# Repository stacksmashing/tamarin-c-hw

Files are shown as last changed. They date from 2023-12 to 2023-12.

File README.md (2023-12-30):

# Tamarin-C Hardware

This is the PCB for the [Tamarin-C firmware](https://github.com/stacksmashing/tamarin-c).

A tool to explore USB-C on Apple devices using the [Tamarin C Hardware](https://github.com/stacksmashing/tamarin-c-hw).

It is based on the [Central Scrutinizer by Marc Zyngier](https://git.kernel.org/pub/scm/linux/kernel/git/maz/cs-hw.git/).

If you're assembling one: An interactive BOM is included with this repository.

## License

This hardware is licensed under [CC BY-NC](https://creativecommons.org/licenses/by-nc/4.0/) - the Creative Commons Attribution-NonCommercial 4.0 International liecnse.

## Thanks

[Aisler](https://aisler.net) was nice enough to make a last-minute run for 37c3 possible, and additionally sponsored a hundred PCBs to give out at the conference. Thanks a lot!

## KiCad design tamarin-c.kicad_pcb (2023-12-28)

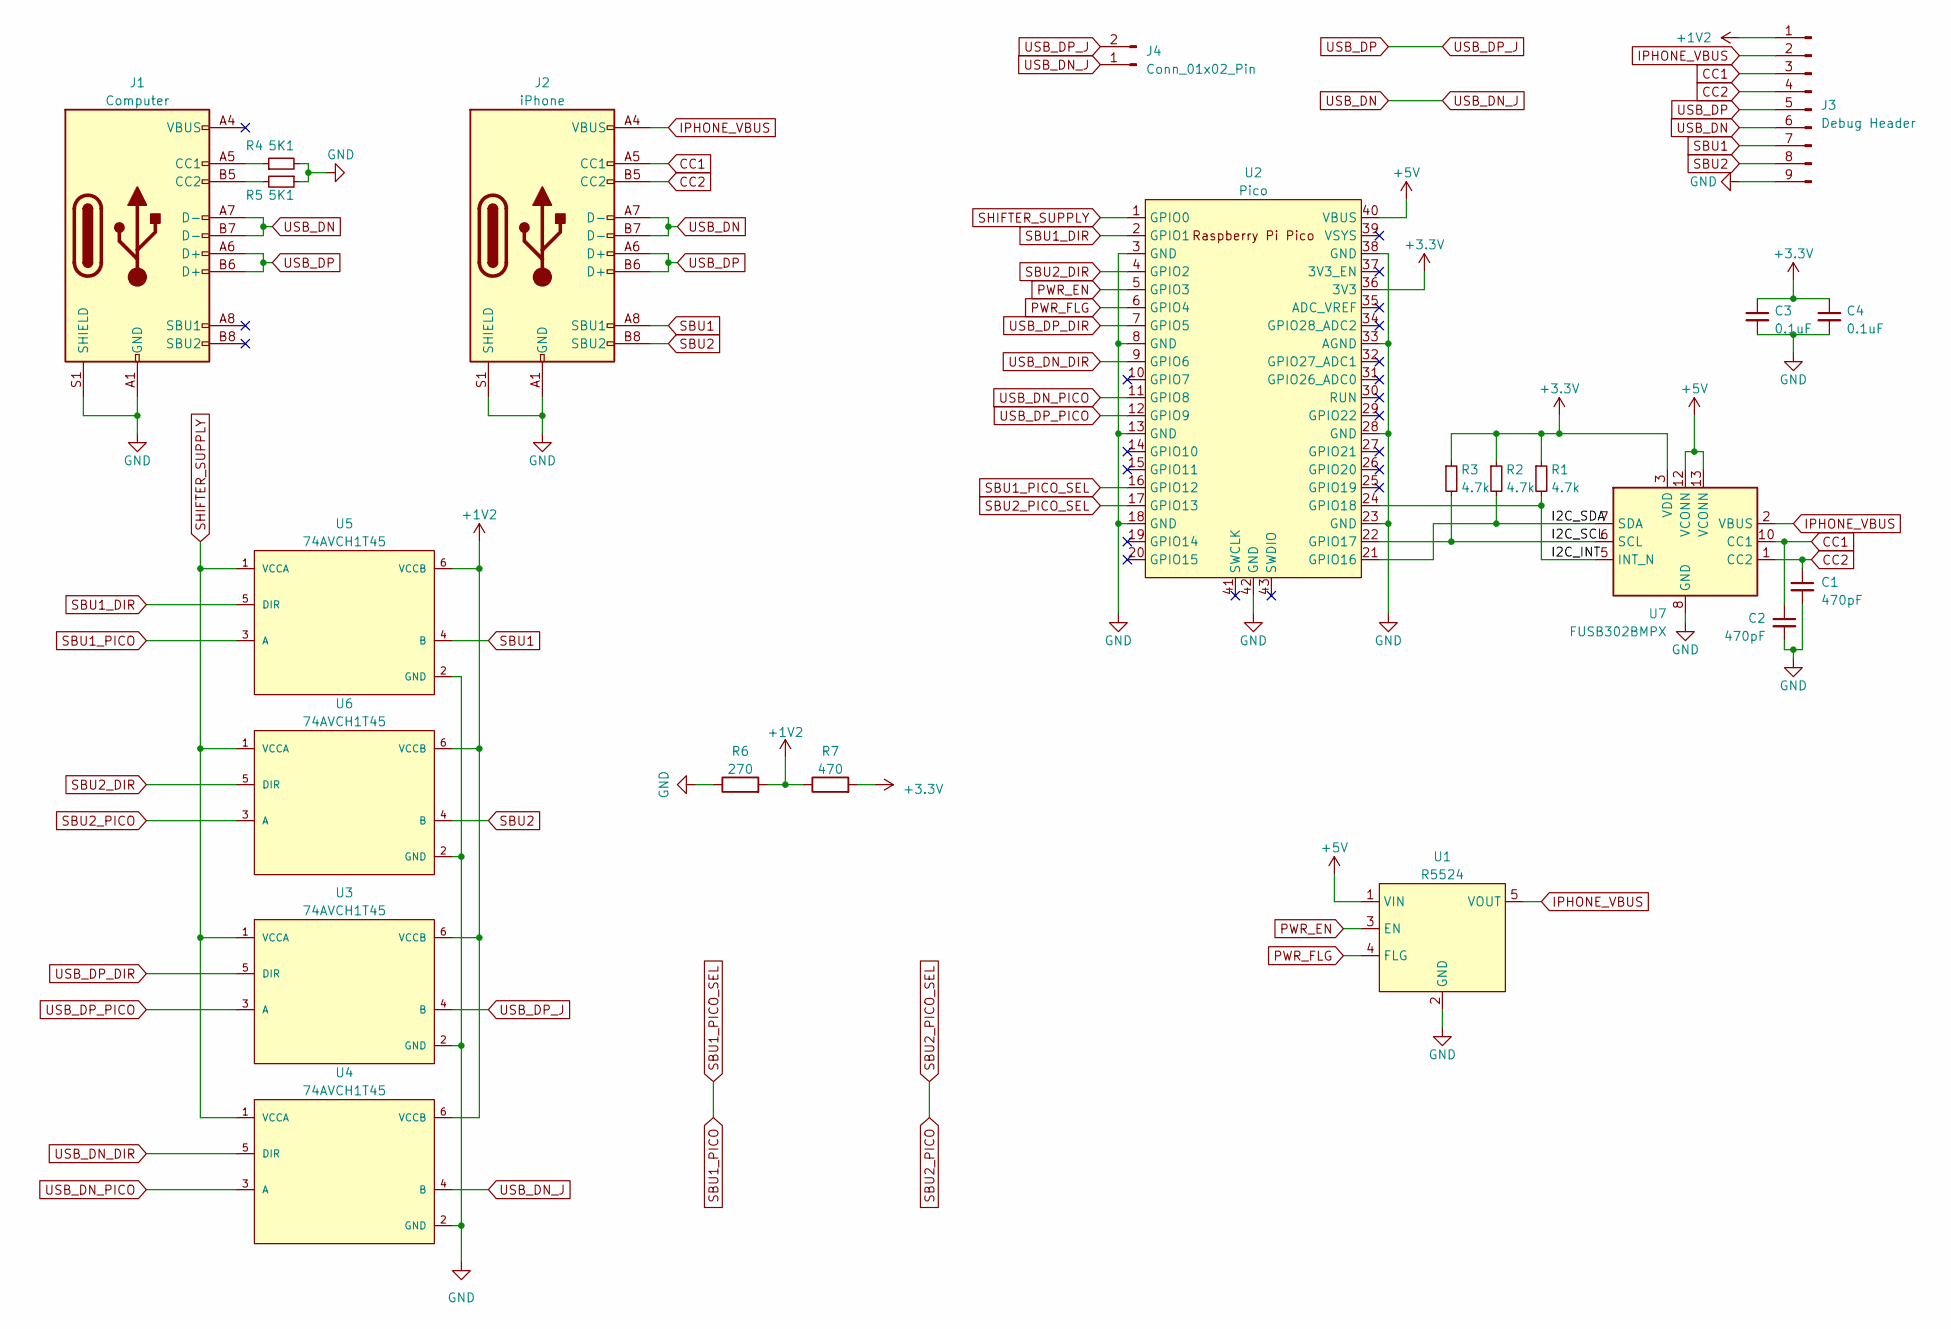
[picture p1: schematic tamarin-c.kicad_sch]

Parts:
C1, C2: 470pF; C_0603_1608Metric
C3, C4: 0.1uF; C_0603_1608Metric; LCSC C1525
J1: Computer; USB_C_Receptacle_HRO_TYPE-C-31-M-12
J2: iPhone; USB_C_Receptacle_HRO_TYPE-C-31-M-12
J3: Debug Header; PinHeader_1x09_P2.54mm_Vertical
J4: Conn_01x02_Pin; PinHeader_1x02_P2.54mm_Vertical
R1, R2, R3: 4.7k; R_0603_1608Metric
R4, R5: 5K1; R_0603_1608Metric
R6: 270; R_0603_1608Metric; LCSC C138294
R7: 470; R_0603_1608Metric; LCSC C25117
U1: R5524; TSOT-23-5; DigiKey 2129-R5524N004A-TR-FECT-ND
U2: Pico; RPi_Pico_SMD_TH
U3, U4, U5, U6: 74AVCH1T45; SOT-23-6; mouser part number 595-SN74AVCH1T45DCKT; digikey description IC TRNSLTR BIDIRECTIONAL SC70-6
U7: FUSB302BMPX; WQFN-14-1EP_2.5x2.5mm_P0.5mm_EP1.45x1.45mm

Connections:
+1V2: J3.1, R6.2, R7.1, U3.6 (VCCB), U4.6 (VCCB), U5.6 (VCCB), U6.6 (VCCB)
+3.3V: C3.1, C4.1, R1.1, R2.1, R3.1, R7.2, U2.36 (3V3), U7.3 (VDD), U7.4 (VDD)
+5V: U1.1 (VIN), U2.40 (VBUS), U7.12 (VCONN), U7.13 (VCONN)
/I2C_INT: R1.2, U2.24 (GPIO18), U7.5 (INT_N)
/I2C_SCL: R3.2, U2.22 (GPIO17), U7.6 (SCL)
/I2C_SDA: R2.2, U2.21 (GPIO16), U7.7 (SDA)
CC1: C2.1, J2.A5 (CC1), J3.3, U7.10 (CC1), U7.11 (CC1)
CC2: C1.1, J2.B5 (CC2), J3.4, U7.1 (CC2), U7.14 (CC2)
GND: C1.2, C2.2, C3.2, C4.2, J1.A1 (GND), J1.A12 (GND), J1.B1 (GND), J1.B12 (GND), J1.S1 (SHIELD), J2.A1 (GND), J2.A12 (GND), J2.B1 (GND), J2.B12 (GND), J2.S1 (SHIELD), J3.9, R4.2, R5.1, R6.1, U1.2 (GND), U2.3 (GND), U2.8 (GND), U2.13 (GND), U2.18 (GND), U2.23 (GND), U2.28 (GND), U2.33 (AGND), U2.38 (GND), U2.42 (GND), U3.2 (GND), U4.2 (GND), U5.2 (GND), U6.2 (GND), U7.8 (GND), U7.9 (GND), U7.15 (GND); also elsewhere on the board
IPHONE_VBUS: J2.A4 (VBUS), J2.A9 (VBUS), J2.B4 (VBUS), J2.B9 (VBUS), J3.2, U1.5 (VOUT), U7.2 (VBUS)
unnamed 10: J1.A5 (CC1), R4.1; also elsewhere on the board
unnamed: J1.B5 (CC2), R5.2
PWR_EN: U1.3 (EN), U2.5 (GPIO3)
PWR_FLG: U1.4 (FLG), U2.6 (GPIO4)
SBU1: J2.A8 (SBU1), J3.7, U5.4 (B)
SBU1_DIR: U2.2 (GPIO1), U5.5 (DIR)
SBU1_PICO: U2.16 (GPIO12), U5.3 (A)
SBU2: J2.B8 (SBU2), J3.8, U6.4 (B)
SBU2_DIR: U2.4 (GPIO2), U6.5 (DIR)
SBU2_PICO: U2.17 (GPIO13), U6.3 (A)
SHIFTER_SUPPLY: U2.1 (GPIO0), U3.1 (VCCA), U4.1 (VCCA), U5.1 (VCCA), U6.1 (VCCA)
USB_DN: J1.A7 (D-), J1.B7 (D-), J2.A7 (D-), J2.B7 (D-), J3.6, J4.1, U4.4 (B)
USB_DN_DIR: U2.9 (GPIO6), U4.5 (DIR)
USB_DN_PICO: U2.11 (GPIO8), U4.3 (A)
USB_DP: J1.A6 (D+), J1.B6 (D+), J2.A6 (D+), J2.B6 (D+), J3.5, J4.2, U3.4 (B)
USB_DP_DIR: U2.7 (GPIO5), U3.5 (DIR)
USB_DP_PICO: U2.12 (GPIO9), U3.3 (A)

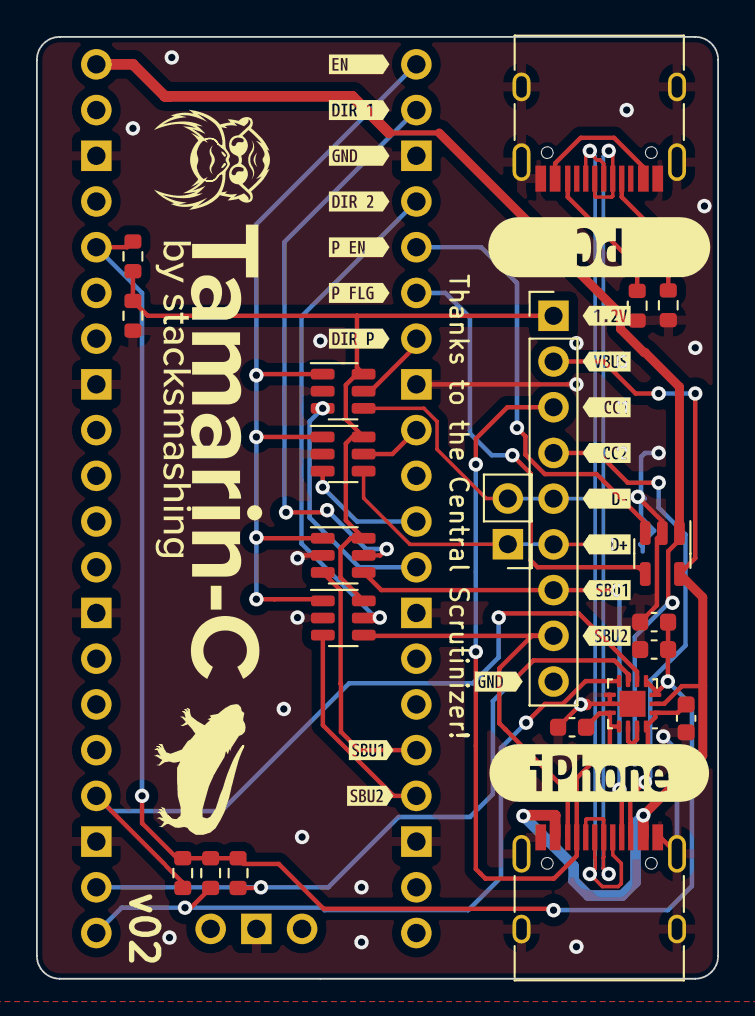
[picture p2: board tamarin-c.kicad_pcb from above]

Board: 2 copper layers, 37.8 x 52.3 mm, 42 parts (1 on the bottom side), 27 nets.

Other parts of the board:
Re: 5K1; R_0603_1608Metric
kibuzzard-656E4D9B: G***; kibuzzard-656E4D9B
kibuzzard-656E4D96: G***; kibuzzard-656E4D96
kibuzzard-656E47A2: G***; kibuzzard-656E47A2
kibuzzard-656E47C5: G***; kibuzzard-656E47C5
kibuzzard-656E47CA: G***; kibuzzard-656E47CA
kibuzzard-656E48C1: G***; kibuzzard-656E48C1
kibuzzard-656E48C5: G***; kibuzzard-656E48C5
kibuzzard-656E48C9: G***; kibuzzard-656E48C9
kibuzzard-656E48CC: G***; kibuzzard-656E48CC
kibuzzard-656E48CF: G***; kibuzzard-656E48CF
kibuzzard-656E48D3: G***; kibuzzard-656E48D3
kibuzzard-656E48D7: G***; kibuzzard-656E48D7
kibuzzard-656E48DB: G***; kibuzzard-656E48DB
kibuzzard-656E51B5: G***; kibuzzard-656E51B5
kibuzzard-656E51BD: G***; kibuzzard-656E51BD
kibuzzard-656E479E: G***; kibuzzard-656E479E
kibuzzard-656E4785: G***; kibuzzard-656E4785
kibuzzard-656E4795: G***; kibuzzard-656E4795
kibuzzard-657EFD91: G***; kibuzzard-657EFD91
kibuzzard-657F00AC: G***; kibuzzard-657F00AC

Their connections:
GND: Re.2; also elsewhere on the board
unnamed 10: Re.1; also elsewhere on the board
